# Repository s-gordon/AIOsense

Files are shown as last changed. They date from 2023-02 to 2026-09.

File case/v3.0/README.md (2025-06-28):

# README

Please note that the ball joint components have been adapted from [Open Source Universal Ball Joint (to reuse!)](https://www.thingiverse.com/thing:4739696) and [Ball Joint Speaker Mount](https://www.thingiverse.com/thing:5429153). These models have been licensed under the [Creative Commons - Attribution - Share Alike](https://creativecommons.org/licenses/by-sa/3.0/) license.

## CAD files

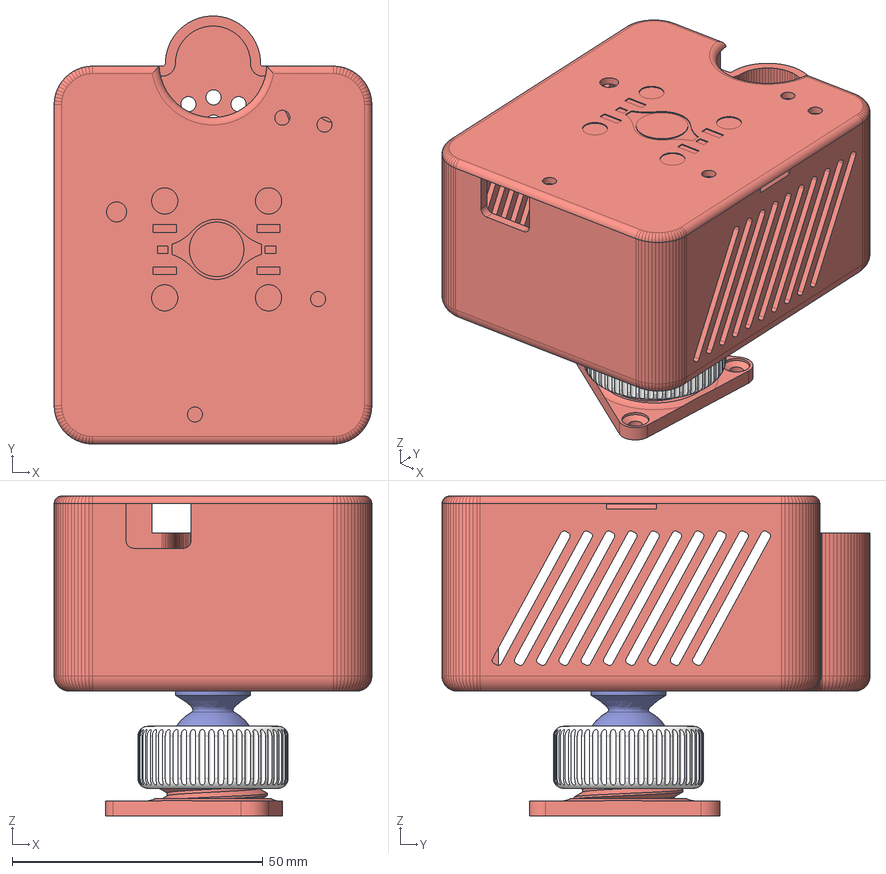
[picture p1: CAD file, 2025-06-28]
case/v3.0/step/case.step
63.4 x 85.4 x 63.8 mm
Ball
Bottom
Lid

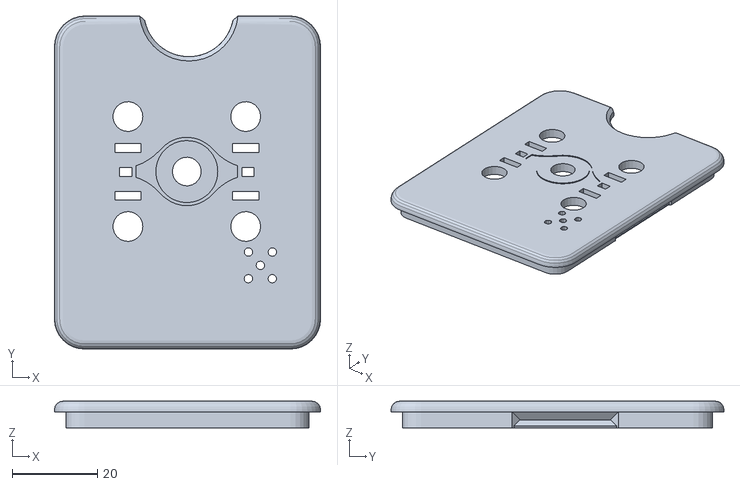
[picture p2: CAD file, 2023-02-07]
stl/case/top.stl
62.4 x 78.1 x 6.25

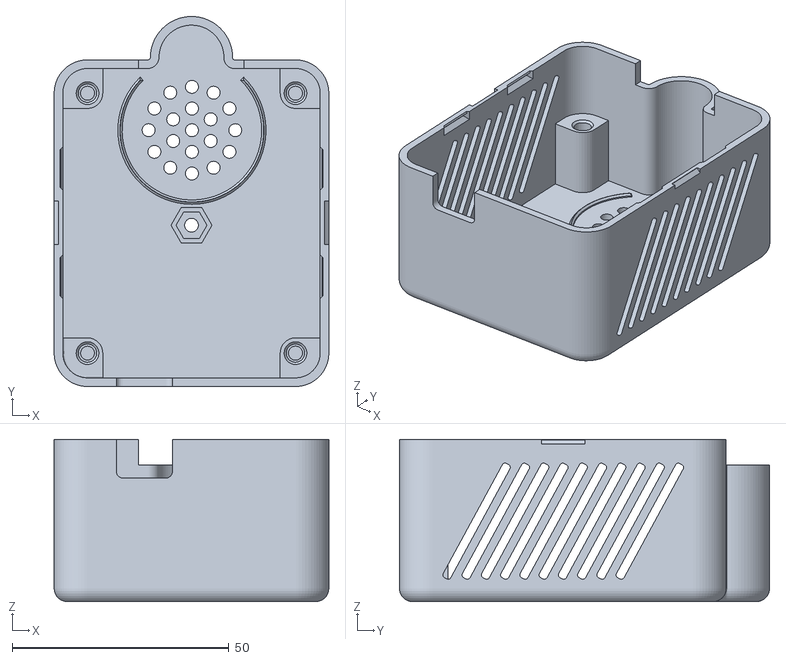
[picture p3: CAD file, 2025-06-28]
case/v3.0/stl/bottom.stl
63.4 x 85.4 x 37.4

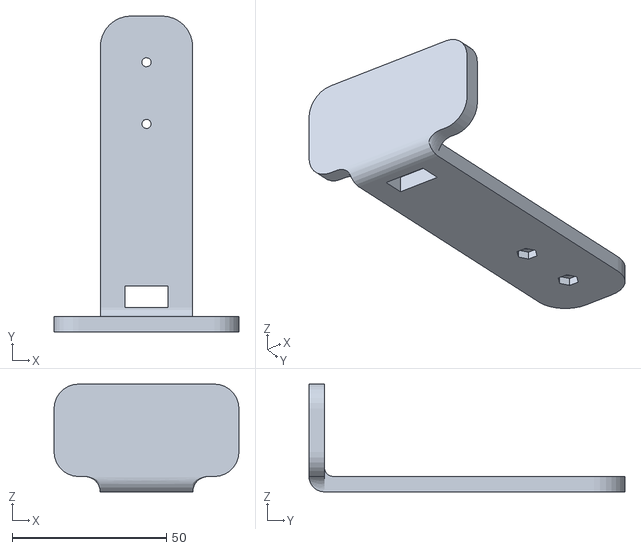
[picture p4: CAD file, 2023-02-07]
stl/case/stand.stl
60.0 x 102.5 x 35.0

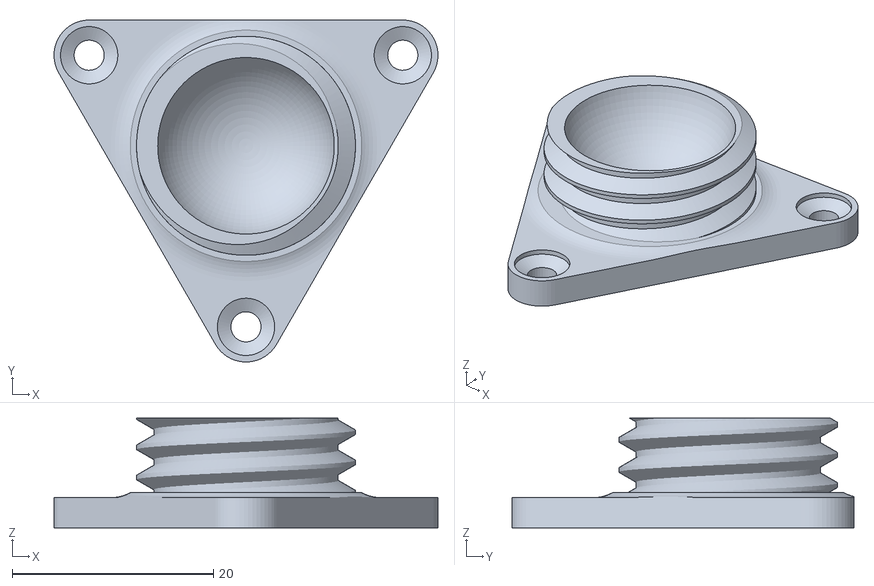
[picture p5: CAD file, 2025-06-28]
case/v3.0/stl/ball_base.stl
38.2 x 34.0 x 10.9

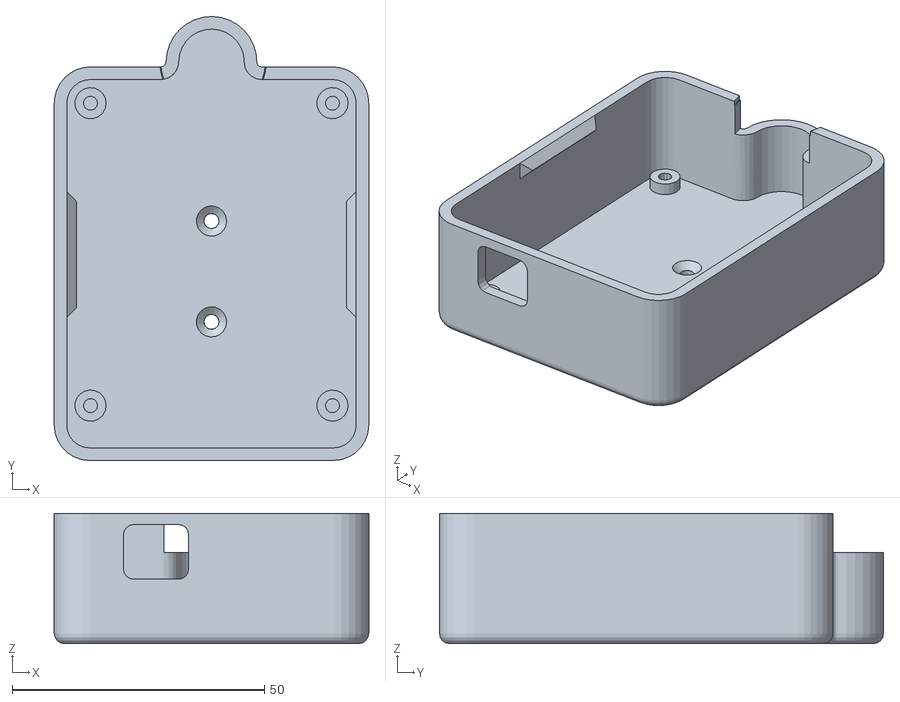
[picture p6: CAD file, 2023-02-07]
stl/case/bottom.stl
62.4 x 88.1 x 25.8

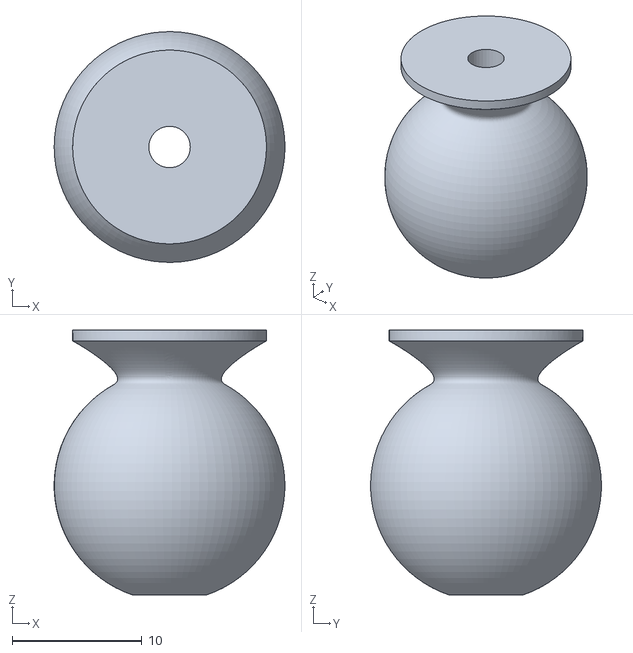
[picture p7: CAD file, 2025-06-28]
case/v3.0/stl/ball.stl
17.8 x 17.8 x 20.4

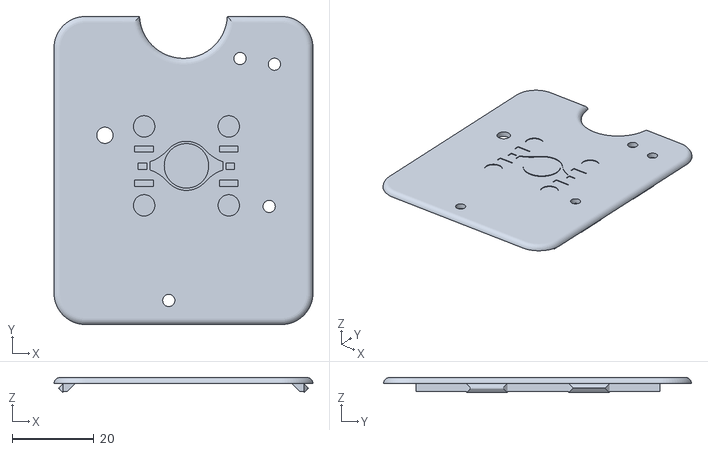
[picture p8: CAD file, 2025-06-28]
case/v3.0/stl/lid.stl
63.4 x 75.4 x 3.70

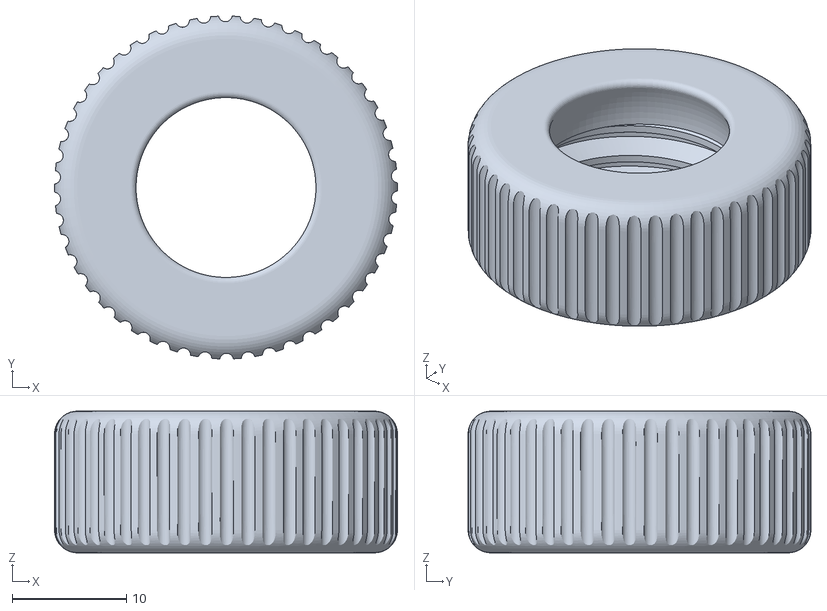
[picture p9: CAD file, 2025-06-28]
case/v3.0/stl/nut.stl
30.0 x 30.0 x 12.4

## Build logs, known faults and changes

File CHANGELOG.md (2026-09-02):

# Changelog

## Historical

Everything below predates this fork's own release tagging and the adoption of
[Conventional Commits](https://www.conventionalcommits.org). It was generated
once with [git-cliff](https://git-cliff.org) from the commit history, using the
upstream release tags as version boundaries, and is preserved verbatim.

`aio-v1.0.0` is the baseline release: everything this fork carried at the point
release automation was adopted. Releases *after* it are managed by
release-please and appear above this section. Do not hand-edit below this line.

## aio-v1.0.0 (2026-09-02)

### Features

- Added Fusion360 file. This is just a zip archive containing several f3d files and accessory JSONs.
- Added pcb-3.0 case draft. Included adjustable wall mount.
- Added sliding window filter to temperature, humidity, pressure from BME280
- Added support for ESP32-S3 mini with speaker-media player. RGB light platform changes for ESP-IDF framework.
- Added speaker-media player introduced in 2025.2.0. ESPHome min version bumped up to 2025.2.0
- Added Fast Pulse and Slow Pulse light effects. Should also now set framework correctly depending on media_player and VA sensors. Added no-PSRAM config for media_player.
- Added esp32 section back in to MP
- Added additional LED effects for media player announcements
- Added wake_word_engine selector. Added micro_wake_word with alexa and hey_jarvis.
- Added speaker to voice assist sensor. Renamed i2s component IDs to improve clarity.
- Added optional media_player sensor
- Status_led ([#288](https://github.com/Schluggi/AIOsense/issues/288))
- Added abilitiy to stop RTTTL playback

### Fixes

- Update LED configuration to use output reference
- Output is a required parameter for light.monochromatic
- Corrected led_invert from bool to str.
- Corrected invert LED back and added arduino framework for C3
- Yaml lint
- Fix: amp swapped terminal label
- Fix pcb version number

### Refactoring

- Renamed i2s_audio to avoid clash with esphome. Removed ESPhome min version declaration
- Switching framework in media_player is problematic
- Python action
- Move to requirements.in
- Move GY-302

### Removals

- Removed esp32 from media_player
- Removed use_wake_word switch
- Removed obsolete boards.
- Tindie link

### Maintenance

- Update esp-idf framework version from latest to recommended
- Enforce arduino frameword for media_player
- Update board for s2 and c3
- Updated pin assignments for rc1. Added i2s_dout_pin for amplifier/speaker.

### Other

- Change to status_led platform for onboard LED
- Do not start voice assist on boot.
- ESPhome 2025.2 changes. Removed declaration of framework in VA instead inherit from parent config for board.
- On device micro wake word crashes on ESP32-S2 mini. HA only.
- PSRAM required
- Typo in platform name
- LED effects not supported on GPIO platform. Switched to monochromatic and ledc
- Invert LED on C3 mini
- OTABackend separation due to PR 6459 in esphome
- OTABackend separation due to https://github.com/esphome/esphome/pull/6459
- Bring back sensor IO positions from V2.1
- Undo project settings
- Initial PCB V3.0.0 commit

## esphome-v3.0.1 (2024-02-25)

### Maintenance

- Update bme280.yaml

### Other

- Release esphome-v3.0.1
- Remake README.md
- Yaml lint

## esphome-v3.0.0 (2023-11-27)

### Features

- Add support for voice assistant with single color leds
- Adding unit_of_measurement
- Adding distance segment zones (closes [#107](https://github.com/Schluggi/AIOsense/issues/107))
- Add basic support for S3 mini
- Add substitutions for voice assistant
- Add pulse effect for booting
- Adding min_version for bsec
- Adding on_boot priority
- Adding default temperature offset
- Adding voice assistant
- Add effects to RGB LED ([#102](https://github.com/Schluggi/AIOsense/issues/102))
- Adding hint to docs for LD2410(c)

### Fixes

- Fixing mmwave_segments
- Fixing S3 led type
- Fixing S3 led colors
- Fixing defaults
- Fixing comments
- Fix breaking changes in 2023.08 ([#105](https://github.com/Schluggi/AIOsense/issues/105))
- Added mmWave to BOM

### Refactoring

- Rename comments

### Removals

- Remove line-length from linting ([#103](https://github.com/Schluggi/AIOsense/issues/103))

### Maintenance

- Bump remote_package version
- Bump s3 framework version
- Bump Ld2410  ([#118](https://github.com/Schluggi/AIOsense/issues/118))

### Other

- Improve mmwave_segments
- Replacing the sen0395 component the new official one (closes [#125](https://github.com/Schluggi/AIOsense/issues/125))
- Led debugging
- Revert "add pulse effect for booting"
- Set version to 3.0.0
- Testing
- Set v3 as package ref
- New docs theme
- BSEC Quickfix ([#122](https://github.com/Schluggi/AIOsense/issues/122))
- Changed github Name from MeisterGig to lukas-holzner ([#127](https://github.com/Schluggi/AIOsense/issues/127))
- Offset improvements ([#111](https://github.com/Schluggi/AIOsense/issues/111))
- Yaml lint
- Swapping rx & tx (closes [#97](https://github.com/Schluggi/AIOsense/issues/97))
- Hanging restore_state to restore_mode  (fixes [#95](https://github.com/Schluggi/AIOsense/issues/95))

## [3.0.1](https://github.com/s-gordon/AIOsense/compare/aio-v3.0.0...aio-v3.0.1) (2026-09-02)

### Fixes

* read the wake word select with select.is, not a removed C++ member ([279dda1](https://github.com/s-gordon/AIOsense/commit/279dda1753608013d1f7b4693a75303b31ba3dbe))
* read the wake word select with select.is, not a removed C++ member ([2388089](https://github.com/s-gordon/AIOsense/commit/2388089d6cc5af94e6c3944f0edfa06547dd275d))

## [3.0.0](https://github.com/s-gordon/AIOsense/compare/aio-v2.0.0...aio-v3.0.0) (2026-09-02)

### ⚠ BREAKING CHANGES

* ESPHome 2026.8.0 or newer is now required. Installs older than that will fail the min_version check instead of building. Configs pinned to aio-v2.0.0 or earlier are unaffected until they move.

### Features

* adopt channel_colors and raise the ESPHome floor to 2026.8.0 ([88e0a3b](https://github.com/s-gordon/AIOsense/commit/88e0a3bd7284225016749e0155ecc025c5a4a4ac))

## [2.0.0](https://github.com/s-gordon/AIOsense/compare/aio-v1.0.2...aio-v2.0.0) (2026-09-02)

### ⚠ BREAKING CHANGES

* esphome/packages/sensors/media_player-psram.yaml is now esphome/packages/sensors/media_player.yaml. Device configs fetch packages by exact path, so any config listing the old path will fail to build once it moves to this release. Update the `files:` entry when bumping `ref:`. Configs pinned to aio-v1.0.2 or earlier are unaffected until they move.

### Fixes

* consolidate to a single working media_player package ([58bd33e](https://github.com/s-gordon/AIOsense/commit/58bd33e5f424e69c719b3518325ebe4b80f12746))

## [1.0.2](https://github.com/s-gordon/AIOsense/compare/aio-v1.0.1...aio-v1.0.2) (2026-09-02)

### Fixes

* drop led_invert declarations that never take effect ([eaed307](https://github.com/s-gordon/AIOsense/commit/eaed307bc8984f9688aebce73822e9f4bac429d7))
* drop led_invert declarations that never take effect ([cd86563](https://github.com/s-gordon/AIOsense/commit/cd8656342437b1c7ba4e43f3fd7e82f9198a1395))

## [1.0.1](https://github.com/s-gordon/AIOsense/compare/aio-v1.0.0...aio-v1.0.1) (2026-09-01)

### Fixes

* make status_led usable with the audio packages ([7deaa63](https://github.com/s-gordon/AIOsense/commit/7deaa6358638d60cceb89572ff014886d8aabcf5))
* remove orphaned gitlink from an esphome build directory ([3f5988a](https://github.com/s-gordon/AIOsense/commit/3f5988a399f29c91030d3ec1663fcbcf4352dcbf))
* stop two packages weakening the min_version floor ([ee7292b](https://github.com/s-gordon/AIOsense/commit/ee7292b909eaf2c9cec4522ffbeb5714700fbec0))
* unpin esp-idf 5.3.1 in the LED voice assistant ([765a36b](https://github.com/s-gordon/AIOsense/commit/765a36b129561b2d10086f4cdb96e7a93bf7fae0))

## v2.1.0 (2023-06-20)

### Features

- **case**: Files for the upright stand mount ([#80](https://github.com/Schluggi/AIOsense/issues/80))
- Quickstart guide for flashing ([#48](https://github.com/Schluggi/AIOsense/issues/48))
- Tindie shop link
- Bme address note
- Make bme i²c address configurable
- 3d printable case (closes [#9](https://github.com/Schluggi/AIOsense/issues/9))
- Safe_mode & cpu temperature
- Sensors for wifi signal and status
- PCBWay references
- Support for HLK-LD2410C ([#33](https://github.com/Schluggi/AIOsense/issues/33))
- BOM ([#48](https://github.com/Schluggi/AIOsense/issues/48))
- Pulldown for PIR ([#52](https://github.com/Schluggi/AIOsense/issues/52))
- Step files for PIR an socket
- PIR description
- 3D image for buzzer
- Own PIR footprint
- RTTTL Buzzer (closes [#32](https://github.com/Schluggi/AIOsense/issues/32))

### Fixes

- Yaml lint
- S2 config (fixes [#79](https://github.com/Schluggi/AIOsense/issues/79)) ([#82](https://github.com/Schluggi/AIOsense/issues/82))
- CPU Temperature sensor only for ESP8266 ([#78](https://github.com/Schluggi/AIOsense/issues/78))
- PIR pin mode for ESP8266 ([#78](https://github.com/Schluggi/AIOsense/issues/78))
- Led invert for ESP8266 ([#78](https://github.com/Schluggi/AIOsense/issues/78))
- MmWave naming
- Fixing reference in demo config
- BOM links
- Debugging I²C based on new package mode
- Kicad error caused by old library
- Fix doc links in README.md
- BME header pin orientation (closes [#55](https://github.com/Schluggi/AIOsense/issues/55))

### Refactoring

- Moved case files to v1.0 sub dir (related to [#57](https://github.com/Schluggi/AIOsense/issues/57))

### Removals

- Restart duplication
- Disable bluetooth_proxy by default (performance problems)
- _pcb.md
- Disable web_server by default

### Other

- 2.1.0
- Safe_mode category to diagnostic
- Yaml lint
- Versioning
- MmWave config is now entity_category: config
- Release 2.1.0-rc1
- Autoformat
- New amazon links
- Resistors footprint to handsolder
- Change resistors from THT to SMD and add LCSC references ([#65](https://github.com/Schluggi/AIOsense/issues/65))
- Use packages to cleanup ESPhome configs ([#70](https://github.com/Schluggi/AIOsense/issues/70))
- Yaml lint for yaml lint
- Cleanup mkdocs
- More strict yaml rules
- ESPHome config updates for HLK-LD2410 ([#45](https://github.com/Schluggi/AIOsense/issues/45))
- Automerge also for minor versions
- Cleanup requirements.txt
- Yaml lint only on yaml changes
- Requirements test only on changes
- Kicad default text width to fix some warnings
- Swapped GND and SDA at the IO port

## v2.0.0 (2023-03-28)

### Features

- Python_requirements.yaml workflow
- Version to bug report
- Debugging for I²C ([#44](https://github.com/Schluggi/AIOsense/issues/44))
- TO-5 digi-key link ([#48](https://github.com/Schluggi/AIOsense/issues/48))
- Added missing bsec config (fixes [#43](https://github.com/Schluggi/AIOsense/issues/43))
- Yaml lint (closes [#39](https://github.com/Schluggi/AIOsense/issues/39))
- Issue templates (closes [#38](https://github.com/Schluggi/AIOsense/issues/38))
- Contributors listing
- Venv
- Add renovate.json
- Docs badge
- Add readthedocs
- Added fillet to bottom hole edge for fit
- Added STL and STEP case models for v1.0.
- Add LCSC part number for JLCPCB SMT services.
- 3s LED while booting (no green, because does not work)
- 3s green LED while booting
- Control for ESP32C3 onboard LED
- BME680 support for EPS32-C3
- Added MH-ET Live as commented out option for board.
- Added ESPHome yaml config for generic ESP32 D1 Mini
- Off_delay for PIR
- Info about the power consumption
- Support for BME680 bsec
- Web_server
- Support for bluetooth_proxy for the esp32-c3
- Project & version
- Order images
- PIR not working note
- Static ip option
- Doc images
- Create ESP Home config for S2 Mini
- Config for esp32 c3 mini
- Reschandreas to special thanks list
- Step file to gitignore
- Qrcode ([#5](https://github.com/Schluggi/AIOsense/issues/5))
- Added: pin header for HLK-LD2410 (closes [#10](https://github.com/Schluggi/AIOsense/issues/10))

### Fixes

- Yaml lint
- Syntax
- Fixed typo - it's not "pulluted" but "polluted"
- PIR pin since PIR changes
- Footprint for LD2410
- Fixed IO labeling (closes [#17](https://github.com/Schluggi/AIOsense/issues/17))
- Typo
- Sensor Modules link
- PIR is now in the center and does not block the mmWave
- PIR sensor pin
- Yaml layout
- Some layout fixes
- Top corners
- PIR label is not in the center of the ESP
- PIR GPIO for S2
- Unify esphome files
- Kicad paths in gitignore

### Refactoring

- Moved the ESP closer to the edge
- Refactor README.md

### Documentation

- Readme rework

### Removals

- Title prefix from doc template
- DependencyDashboard
- Changelog (look at releases)
- Password for fallback ap
- Bluetooth_proxy (no tested yet)
- Everything v1 related

### Maintenance

- Requirements.txt
- Updated model to correct problems from test print
- Updated step file to mirror changes in top/bottom
- Updated top component to shorten pins
- Updated part numbers for as many parts as possible for Mouser, Farnell, Digikey (and the HiLink LD2410 with Aliexpress Link)
- Images & schematic
- Pcb images
- Date on schematic
- Schematic and date

### Other

- Release of v2.0.0
- Yaml lint
- YAML lint
- Automerge patches (renovate)
- Closes [#47](https://github.com/Schluggi/AIOsense/issues/47) - new light for esp32 d1 mini that is trigerred on boot
- Downgrade markdown
- Improve docs ([#31](https://github.com/Schluggi/AIOsense/issues/31))
- Improve docs (closes [#31](https://github.com/Schluggi/AIOsense/issues/31))
- Anyway... all yaml files
- Yaml lint only for esphome/
- Myst-parser to 1.0.0
- Filename
- Note not to buy v1
- Migration to kicad 7.0
- Restored group id
- Power pins replaced with terminal block (closes [#18](https://github.com/Schluggi/AIOsense/issues/18))
- PIR-Jumper removed & port labels changed
- MmWave Distance: box is now a slider
- Illuminance update_interval
- Small layout changes
- Product images added, badges changed
- Mounting holes now are grounded
- Changed: PCB size reduced
- Back to THT resistors (closes [#12](https://github.com/Schluggi/AIOsense/issues/12))
- Switch to SMD (closes [#12](https://github.com/Schluggi/AIOsense/issues/12))
- PCB review changes
- All-in-one-sensor is now AIOsense
- Closes [#3](https://github.com/Schluggi/AIOsense/issues/3): m3 mounting holes

## v1.0 (2022-11-07)

### Documentation

- README.md

### Other

- First release

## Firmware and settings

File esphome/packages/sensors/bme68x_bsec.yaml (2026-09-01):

substitutions:
  bme_address: "0x76"
  co2_offset: "0"
  humidity_offset: "0"
  iaq_offset: "0"
  pressure_offset: "0"
  temperature_offset: "0"
  voc_offset: "0"

external_components:
  - source: github://schluggi/esphome@dev
    components:
      - bme68x_bsec

bme68x_bsec:
  address: "${bme_address}"
  bsec_configuration: 0,0,2,2,189,1,0,0,0,0,0,0,213,8,0,0,52,0,1,0,0,192,168,71,64,49,119,76,0,0,97,69,0,0,97,69,137,65,0,63,0,0,0,63,0,0,64,63,205,204,204,62,10,0,3,0,216,85,0,100,0,0,96,64,23,183,209,56,28,0,2,0,0,244,1,150,0,50,0,0,128,64,0,0,32,65,144,1,0,0,112,65,0,0,0,63,16,0,3,0,10,215,163,60,10,215,35,59,10,215,35,59,13,0,5,0,0,0,0,0,100,35,41,29,86,88,0,9,0,229,208,34,62,0,0,0,0,0,0,0,0,218,27,156,62,225,11,67,64,0,0,160,64,0,0,0,0,0,0,0,0,94,75,72,189,93,254,159,64,66,62,160,191,0,0,0,0,0,0,0,0,33,31,180,190,138,176,97,64,65,241,99,190,0,0,0,0,0,0,0,0,167,121,71,61,165,189,41,192,184,30,189,64,12,0,10,0,0,0,0,0,0,0,0,0,173,6,11,0,1,2,2,207,61,208,65,149,110,24,66,180,108,177,65,219,148,13,192,70,132,58,66,163,58,140,192,12,99,178,192,185,59,255,193,178,213,175,63,0,0,0,0,0,0,0,0,0,0,0,0,0,0,0,0,0,0,0,0,0,0,0,0,0,0,0,0,0,0,0,0,0,0,0,0,0,0,0,0,0,0,0,0,110,211,55,195,237,6,56,67,0,0,0,0,0,0,0,0,26,3,255,63,61,246,7,192,171,201,228,192,249,144,215,63,237,199,104,193,128,158,216,64,117,140,155,63,137,120,129,67,108,109,253,191,0,0,0,0,81,64,57,68,103,241,231,64,109,29,152,192,209,43,193,63,93,54,30,65,197,46,92,64,128,27,224,192,6,20,144,191,56,179,130,64,0,0,0,0,43,156,59,196,33,217,100,194,104,77,72,65,15,103,175,191,249,252,12,193,63,117,253,192,233,5,141,65,155,42,25,64,13,88,249,191,0,0,0,0,48,141,122,190,204,150,44,192,36,162,29,193,96,59,39,189,54,202,48,65,151,205,68,64,79,105,55,193,53,120,53,192,77,211,32,192,0,0,0,0,193,207,92,65,239,201,76,65,208,70,82,66,81,63,96,65,48,179,0,194,251,96,242,193,176,51,96,194,153,114,98,66,144,247,64,65,0,0,0,0,219,179,180,63,175,218,119,191,51,71,207,191,245,145,129,63,53,16,244,65,138,208,117,65,138,97,36,66,228,15,32,195,126,91,103,191,0,0,0,0,26,151,170,193,64,105,49,193,46,223,189,193,129,203,168,193,40,91,49,66,4,87,107,65,205,202,37,65,244,36,154,66,240,85,39,193,0,0,0,0,166,96,87,192,114,7,68,191,233,32,214,63,84,249,40,192,45,78,132,64,145,33,253,61,49,43,187,192,244,32,77,67,224,250,71,191,0,0,0,0,103,75,214,190,206,141,252,63,99,15,178,65,80,79,166,190,214,25,146,192,165,29,24,194,18,228,219,193,113,246,235,194,49,115,232,63,0,0,0,0,17,211,124,64,56,252,251,62,25,118,148,193,168,234,94,64,131,157,82,64,217,119,236,65,120,245,240,65,17,69,168,195,49,51,8,63,0,0,0,0,0,0,0,0,0,0,0,0,0,0,0,0,0,0,0,0,0,0,0,0,0,0,0,0,0,0,0,0,0,0,0,0,0,0,0,0,0,0,0,0,0,0,0,0,0,0,0,0,0,0,0,0,0,0,0,0,0,0,0,0,0,0,0,0,0,0,0,0,0,0,0,0,0,0,0,0,0,0,0,0,0,0,0,0,0,0,0,0,0,0,0,0,0,0,0,0,0,0,0,0,0,0,0,0,0,0,0,0,0,0,0,0,0,0,0,0,0,0,0,0,0,0,0,0,0,0,0,0,0,0,0,0,0,0,0,0,0,0,0,0,0,0,0,0,0,0,0,0,0,0,0,0,0,0,0,0,0,0,0,0,0,0,0,0,0,0,0,0,0,0,0,0,0,0,0,0,0,0,0,0,0,0,0,0,0,0,0,0,0,0,0,0,0,0,0,0,0,0,0,0,0,0,0,0,0,0,0,0,0,0,0,0,0,0,0,0,0,0,0,0,0,0,0,0,0,0,0,0,0,0,0,0,0,0,0,0,0,0,0,0,0,0,0,0,0,0,0,0,0,0,0,0,0,0,0,0,0,0,0,0,0,0,0,0,0,0,0,0,0,0,0,0,0,0,0,0,0,0,0,0,0,0,0,0,0,0,0,0,0,0,0,0,0,0,0,0,0,0,0,0,0,0,0,0,0,0,0,0,0,0,0,0,0,0,0,0,0,0,0,0,0,0,0,0,0,0,0,0,0,0,0,0,0,0,0,0,0,0,0,0,0,0,0,0,0,0,0,0,0,0,0,0,0,0,0,0,0,0,0,0,0,0,0,0,0,0,0,0,0,0,0,0,0,0,0,0,0,0,0,0,0,0,0,0,0,0,0,0,0,0,0,0,0,0,0,0,0,0,0,0,0,0,0,0,0,0,0,0,0,0,0,0,0,0,0,0,0,0,0,0,0,0,0,0,0,0,0,0,0,0,0,0,0,0,0,0,0,0,0,0,0,0,0,0,0,0,0,0,0,0,0,0,0,0,0,0,0,0,0,0,0,0,0,0,0,0,0,0,0,0,0,0,0,0,0,0,0,0,0,0,0,0,0,0,0,0,0,0,0,0,0,0,0,0,0,0,0,0,0,0,0,0,0,0,0,0,0,0,0,0,0,0,0,0,0,0,0,0,0,0,131,217,97,66,182,104,101,194,0,0,0,0,0,0,0,0,6,142,142,195,229,54,143,67,0,0,0,0,0,0,0,0,25,224,153,66,217,51,154,194,0,0,0,0,0,0,0,0,142,36,105,194,199,63,110,66,0,0,0,0,0,0,0,0,206,73,250,193,138,69,249,65,0,0,0,0,0,0,0,0,123,173,127,66,20,116,128,194,0,0,0,0,0,0,0,0,49,65,49,64,205,213,107,192,0,0,0,0,0,0,0,0,189,250,179,194,164,98,180,66,0,0,0,0,0,0,0,0,96,182,197,67,155,71,197,195,0,0,0,0,0,0,0,0,0,0,0,0,0,0,0,0,0,0,0,0,0,0,0,0,9,0,2,0,0,0,0,0,0,0,0,0,0,0,0,0,0,0,0,0,0,0,0,0,0,0,0,0,0,0,0,0,0,0,0,0,0,0,0,0,0,0,0,0,0,0,0,0,0,0,0,0,0,0,0,0,0,0,0,0,0,0,0,0,0,0,0,0,0,0,0,0,0,0,0,0,0,0,0,0,0,0,0,0,0,0,0,0,0,0,0,0,0,0,0,0,0,0,0,0,0,0,0,0,0,0,0,0,0,0,0,0,0,0,0,0,0,0,0,0,0,0,0,0,0,0,0,0,0,0,0,0,0,0,0,0,0,0,0,0,0,0,0,0,0,0,0,0,0,0,0,0,0,0,0,0,0,0,0,0,0,0,0,0,0,0,0,0,0,0,0,0,0,0,0,0,0,0,0,0,0,0,0,0,0,0,0,0,0,0,0,0,0,0,0,0,0,0,0,0,0,0,0,0,0,0,0,0,0,0,0,0,0,0,0,0,0,0,0,0,0,0,0,0,0,0,0,0,0,0,0,0,0,0,0,0,0,0,0,0,0,0,0,0,0,0,0,0,0,0,0,0,0,0,0,0,0,0,0,0,0,0,0,0,0,0,0,0,0,0,0,0,0,0,0,0,0,0,0,0,0,0,0,0,0,0,0,0,0,0,0,0,0,0,0,0,0,0,0,0,0,0,0,0,0,0,0,0,0,0,0,0,0,0,0,0,0,0,0,0,0,0,0,0,0,0,0,0,0,0,0,0,0,0,0,0,0,0,0,0,0,0,0,0,0,0,0,0,0,0,0,0,0,0,0,0,0,0,0,0,0,0,0,0,0,0,0,0,0,0,0,0,0,0,0,0,0,0,0,0,0,0,0,0,0,0,0,0,0,0,0,0,0,0,0,0,0,0,0,0,0,0,0,0,0,0,0,0,0,0,0,0,0,0,0,0,0,0,0,185,28,179,73,64,25,141,76,223,26,138,76,222,207,133,76,87,134,164,75,23,127,159,75,166,9,155,75,94,120,170,73,9
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

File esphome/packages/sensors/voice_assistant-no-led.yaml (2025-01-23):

i2s_audio:
  - id: i2s_output
    # i2s_output data pin is gpio10
    i2s_lrclk_pin:
      number: ${i2s_out_lrclk_pin}
    i2s_bclk_pin:
      number: ${i2s_out_bclk_pin}

  - id: i2s_input
    i2s_lrclk_pin:
      number: "${i2s_lrclk_pin}"  # WS
    i2s_bclk_pin:
      number: "${i2s_bclk_pin}"  # SCK

microphone:
  - platform: nabu_microphone
    i2s_din_pin: ${i2s_din_pin}
    adc_type: external
    pdm: false
    sample_rate: 16000
    bits_per_sample: 32bit
    i2s_mode: secondary
    i2s_audio_id: i2s_input
    channel_0:
      id: asr_mic
      amplify_shift: 0
    channel_1:
      id: comm_mic
      amplify_shift: 2

speaker:
  - platform: i2s_audio
    sample_rate: 48000
    i2s_mode: secondary
    i2s_dout_pin: ${i2s_speaker_din_pin}
    bits_per_sample: 32bit
    i2s_audio_id: i2s_output
    dac_type: external
    channel: stereo
    timeout: never
    buffer_duration: 100ms

media_player:
  - platform: nabu
    id: nabu_media_player
    name: Media Player
    internal: false
    audio_dac:
    speaker:
    sample_rate: 48000
    volume_increment: 0.05
    volume_min: 0.4
    volume_max: 0.85
    on_mute:
      - script.execute: control_leds
    on_unmute:
      - script.execute: control_leds
    on_volume:
      - script.execute: control_leds
    on_announcement:
      - nabu.set_ducking:
          decibel_reduction: 20
          duration: 0.0s
    on_state:
      if:
        condition:
          and:
            - switch.is_off: timer_ringing
            - not:
                voice_assistant.is_running:
            - not:
                lambda: return id(nabu_media_player)->state == media_player::MediaPlayerState::MEDIA_PLAYER_STATE_ANNOUNCING;
        then:
          - nabu.set_ducking:
              decibel_reduction: 0
              duration: 1.0s
    files:
      - id: center_button_press_sound
        file: https://github.com/esphome/home-assistant-voice-pe/raw/dev/sounds/center_button_press.flac
      - id: center_button_double_press_sound
        file: https://github.com/esphome/home-assistant-voice-pe/raw/dev/sounds/center_button_double_press.flac
      - id: center_button_triple_press_sound
        file: https://github.com/esphome/home-assistant-voice-pe/raw/dev/sounds/center_button_triple_press.flac
      - id: center_button_long_press_sound
        file: https://github.com/esphome/home-assistant-voice-pe/raw/dev/sounds/center_button_long_press.flac
      - id: factory_reset_initiated_sound
        file: https://github.com/esphome/home-assistant-voice-pe/raw/dev/sounds/factory_reset_initiated.mp3
      - id: factory_reset_cancelled_sound
        file: https://github.com/esphome/home-assistant-voice-pe/raw/dev/sounds/factory_reset_cancelled.mp3
      - id: jack_connected_sound
        file: https://github.com/esphome/home-assistant-voice-pe/raw/dev/sounds/jack_connected.flac
      - id: jack_disconnected_sound
        file: https://github.com/esphome/home-assistant-voice-pe/raw/dev/sounds/jack_disconnected.flac
      - id: mute_switch_on_sound
        file: https://github.com/esphome/home-assistant-voice-pe/raw/dev/sounds/mute_switch_on.flac
      - id: mute_switch_off_sound
        file: https://github.com/esphome/home-assistant-voice-pe/raw/dev/sounds/mute_switch_off.flac
      - id: timer_finished_sound
        file: https://github.com/esphome/home-assistant-voice-pe/raw/dev/sounds/timer_finished.flac
      - id: wake_word_triggered_sound
        file: https://github.com/esphome/home-assistant-voice-pe/raw/dev/sounds/wake_word_triggered.flac
      - id: easter_egg_tick_sound
        file: https://github.com/esphome/home-assistant-voice-pe/raw/dev/sounds/easter_egg_tick.mp3
      - id: easter_egg_tada_sound
        file: https://github.com/esphome/home-assistant-voice-pe/raw/dev/sounds/easter_egg_tada.mp3


external_components:
  - source:
      type: git
      url: https://github.com/esphome/voice-kit
      ref: dev
    components:
      - aic3204
      - audio_dac
      - media_player
      - micro_wake_word
      - microphone
      - nabu
      - nabu_microphone
      - voice_assistant
      - voice_kit
    refresh: 0s

voice_kit:
  reset_pin: ${voice_kit_reset_pin}
  firmware:
    url: https://github.com/esphome/voice-kit-xmos-firmware/releases/download/v1.3.1/ffva_v1.3.1_upgrade.bin
    version: "1.3.1"
    md5: 964635c5bf125529dab14a2472a15401
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

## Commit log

2023-02-07 Added initial stls for case.
    [bottom.stl, stand.stl, top.stl]
2023-02-07 Updated case. Light holes expanded for sensor. Made stand longer to allow clearance for USB cable. Lowered PIR sensor to proper height with TO-5 3 pin socket.
    [bottom.stl, stand.stl, top.stl]
2025-01-15 Added draft VA to LED version
2025-01-15 disable led output
2025-01-15 Typo. Remove switch.is_on listen light condition for reset_led
    [voice_assistant-led.yaml]
2025-01-15 Corrected incorrect GPIO pin assignment for speaker and mic
    [voice_assistant-led.yaml]
2025-01-22 platform change from neopixelbus to esp32_rmt_led_strip
2025-01-22 Throttle LD2410
2025-01-22 Correct pin assignments for S3 mini
2025-01-23 Fixed esp32-s3 framework version
2025-01-23 voice assist (no-led and rgb)
2025-01-23 Removed temperature offset
2025-01-23 Brought down brightness of LED for voice assist
2025-01-27 Added more control to switch off voice assist.
2025-01-30 Removed obsolete boards.
2025-01-30 Updated pin assignments for rc1. Added i2s_dout_pin for amplifier/speaker.
2025-01-30 Added optional media_player sensor
2025-01-30 Added speaker to voice assist sensor. Renamed i2s component IDs to improve clarity.
2025-01-30 Removed use_wake_word switch
2025-01-31 Invert LED on C3 mini
2025-01-31 Corrected invert LED back and added arduino framework for C3
2025-01-31 Removed esp32 from media_player
2025-01-31 Added additional LED effects for media player announcements
2025-01-31 LED effects not supported on GPIO platform. Switched to monochromatic and ledc
2025-01-31 Update board for s2 and c3
2025-01-31 Enforce arduino frameword for media_player
2025-01-31 Switching framework in media_player is problematic
2025-01-31 Added esp32 section back in to MP
2025-02-01 Added Fast Pulse and Slow Pulse light effects. Should also now set framework correctly depending on media_player and VA sensors. Added no-PSRAM config for media_player.
    [rgb_led.yaml, voice_assistant-led.yaml, voice_assistant-rgb_led.yaml]
2025-02-01 On device micro wake word crashes on ESP32-S2 mini. HA only.
    [voice_assistant-led.yaml]
2025-02-20 Added support for ESP32-S3 mini with speaker-media player. RGB light platform changes for ESP-IDF framework.
2025-02-21 Corrected led_invert from bool to str.
2025-03-08 ESPhome 2025.2 changes. Removed declaration of framework in VA instead inherit from parent config for board.
2025-03-08 Renamed i2s_audio to avoid clash with esphome. Removed ESPhome min version declaration
    [voice_assistant-rgb_led.yaml]
2026-09-02 fix: drop led_invert declarations that never take effect
    esp32-s2-mini.yaml declared `led_invert: "true"` and esp32-c3-mini.yaml
    declared `"false"`, but neither was ever applied. Board configs are listed
    before sensor packages, and a later package's substitution default wins, so
    led.yaml's `"false"` silently overrode both:
    board before led (the documented order) -> inverted: false
    board after led -> inverted: true
    The S2 declaration was also simply wrong. Confirmed on hardware: with
    `inverted: false` the boot sequence in led.yaml behaves as written -- the LED
    lights for ~2s and then goes dark. GPIO15 on the S2 mini is active-high, so
    "true" would have produc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
    [led.yaml, status_led.yaml]
2026-09-02 fix!: consolidate to a single working media_player package
    There were two media player packages, and the names described the wrong axis.
    media_player.yaml used the `media_player.i2s_audio` platform, which ESPHome has
    removed:
    The I2S audio media player has been removed. Use the speaker media player
    component instead.
    media_player-psram.yaml was already on the modern `speaker:` +
    `media_player: platform: speaker` pipeline and is what every device actually
    runs -- on S3 as well as S2. So the `-psram` suffix never meant PSRAM vs
    non-PSRAM; it meant working vs broken. That mislabelling is why esphome.yaml
    had the dead file *enabled* and annotated "ESP32-S3-mini", while the working one
    was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
2026-09-02 feat!: adopt channel_colors and raise the ESPHome floor to 2026.8.0
    esp32_rmt_led_strip deprecated `rgb_order` in favour of `channel_colors`, with
    removal scheduled for 2027.3.0:
    WARNING [esp32_rmt_led_strip] 'rgb_order' is deprecated, use
    'channel_colors: RGB'. Will be removed in 2027.3.0
    The swap is a straight rename -- `channel_colors` takes the same string form, so
    "${rgb_led_type}" carries over untouched and each board still resolves to its
    own value (S3 RGB, C3 GRB). The ESPHome docs already list `channel_colors` as
    required and no longer mention `rgb_order` at all.
    `channel_colors` first appears in ESPHome 2026.8.0 -- checked 2025.2.0 through
    2026.7.0, absent in all of them --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
    [rgb_led.yaml]
2026-09-02 fix: read the wake word select with select.is, not a removed C++ member
    Both voice assistant packages tested the wake word selector through a lambda
    reading `.state`:
    lambda: return id(wake_word_engine_location).state == "In Home Assistant";
    ESPHome's Select class no longer has a `state` member -- it has been gone since
    before 2026.2.0, replaced by `current_option()` returning a StringRef. Builds
    fail at compile time:
    error: 'class esphome::template_::TemplateSelect<false, true, true, 1>'
    has no member named 'state'
    `esphome config` accepts these files regardless, because a lambda body is opaque
    to schema validation and is only checked once it reaches the compiler. That is
    why CI h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
    [voice_assistant-led.yaml, voice_assistant-rgb_led.yaml]
